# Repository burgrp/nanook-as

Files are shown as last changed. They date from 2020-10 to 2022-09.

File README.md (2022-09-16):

# nanook-as
NANOOK analog sensors board

|COLD |WATER IN |WATER OUT|FRIGO IN|FRIGO OUT|
|---|---|---|---|---|
| | R5 | R6 | R7 | R8 |
| t |-15..15  |-15..15  |-15..15 |-15..15  |
| R |56k |56k |56k |56k |

|HOT |WATER IN |WATER OUT|FRIGO IN|FRIGO OUT|
|---|---|---|---|---|
| | R5 | R6 | R7 | R8 |
| t |10..60 |10..70 |10..130 |10..60 |
| R1 |4k7 |4k7 |1k5 |4k7 |

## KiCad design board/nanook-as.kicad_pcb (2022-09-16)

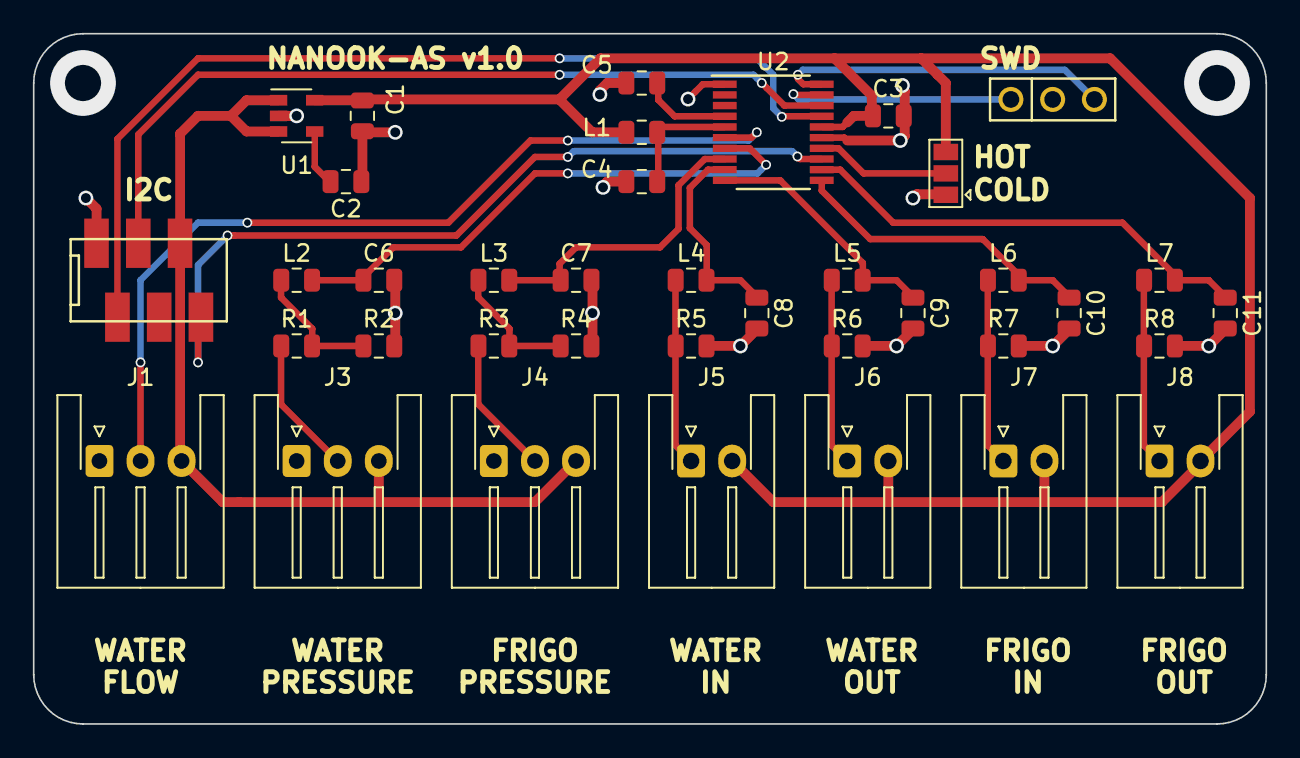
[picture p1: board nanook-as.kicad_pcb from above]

Board: 2 copper layers, 75.0 x 42.0 mm, 38 parts (0 on the bottom side), 27 nets.

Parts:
C1: 1u; C_0805_2012Metric
C2: 10n; C_0805_2012Metric
C3, C4, C5, C6, C7, C8, C9, C10, C11: 100n; C_0805_2012Metric
J1: Water Flow; JST_XH_S3B-XH-A-1_1x03_P2.50mm_Horizontal
J2: Address; SolderJumper-3_P1.3mm_Open_Pad1.0x1.5mm
J3, J4: Conn_01x03; JST_XH_S3B-XH-A-1_1x03_P2.50mm_Horizontal
J5, J6, J7, J8: Conn_01x02; JST_XH_S2B-XH-A-1_1x02_P2.50mm_Horizontal
L1, L2, L3, L4, L5, L6, L7: 22uH; L_0805_2012Metric
R1, R3: 4k7; R_0805_2012Metric
R2, R4: 10k; R_0805_2012Metric
R5, R6, R7, R8: (README.md); R_0805_2012Metric
U1: SPX3819; SOT-23-5
U2: STM32F030F4Px; TSSOP-20_4.4x6.5mm_P0.65mm
X1: I2C-6P; Micro-Match-FOB-6
X2: SWD

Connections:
+3V3: C1.2, C3.1, J2.3 (B), J5.2, J6.2, J7.2, J8.2, L1.1, U1.5 (VOUT), U2.16 (VDD)
+5V: J1.3, J3.3, J4.3, U1.1 (VIN), U1.3 (EN), X1.5 (5V)
/ALERT: U2.13 (PA7), X1.6 (ALERT)
/Frigo In/ADC-IN: C10.1, L6.2, U2.11 (PA5)
/Frigo Out/ADC-IN: C11.1, L7.2, U2.12 (PA6)
/Frigo Pressure/ADC-IN: C7.1, L3.2, U2.8 (PA2)
/SCL: U2.17 (PA9), X1.2 (SCL)
/SDA: U2.18 (PA10), X1.3 (SDA)
/SWCLK: U2.20 (PA14), X2.3 (SWCLK)
/SWDIO: U2.19 (PA13), X2.1 (SWDIO)
/Water In/ADC-IN: C8.1, L4.2, U2.9 (PA3)
/Water Out/ADC-IN: C9.1, L5.2, U2.10 (PA4)
/Water Pressure/ADC-IN: C6.1, L2.2, U2.7 (PA1)
GND: C1.1, C2.1, C3.2, C4.1, C5.2, C6.2, C7.2, C8.2, C9.2, C10.2, C11.2, J1.1, J2.1 (A), J3.1, J4.1, R2.2, R4.2, R5.2, R6.2, R7.2, R8.2, U1.2 (GND), U2.1 (BOOT0), U2.15 (VSS), X1.1 (GND), X2.2 (GND)
unnamed: J1.2, U2.6 (PA0)
unnamed: J2.2 (C), U2.14 (PB1)
unnamed: J3.2, R1.1
unnamed: J4.2, R3.1
unnamed: J5.1, L4.1, R5.1
unnamed: J6.1, L5.1, R6.1
unnamed: J7.1, L6.1, R7.1
unnamed: J8.1, L7.1, R8.1
unnamed: L2.1, R1.2, R2.1
unnamed: L3.1, R3.2, R4.1
unnamed: C2.2, U1.4 (BP)
unnamed: C5.1, U2.4 (NRST)
unnamed: C4.2, L1.2, U2.5 (VDDA)

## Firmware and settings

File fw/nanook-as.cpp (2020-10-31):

#include <climits>

const int analogSensCount = 8;
const int analogSensBaseIdx = 1;	

class IAS3 {

	iwdg::Driver iwdg;
	short data[1 + analogSensCount];

public:

	i2c::hw::BufferedSlave i2c;
	FrequencyMeter frequencyMeter;
	PeriodicAdc adc;

	void init(volatile target::i2c::Peripheral* peripheral, int address) {
		for (int i = 0; i < sizeof(data) / sizeof(data[0]); i++) {
			data[i] = 0;
		}
		iwdg.init();
		i2c.init(peripheral, address, NULL, 0, (unsigned char*)&data, sizeof(data));
		frequencyMeter.init(0, &data[0]);
		adc.init(&data[1], analogSensCount, analogSensBaseIdx);		
	}

};

IAS3 ias3;

void interruptHandlerI2C1() {
	ias3.i2c.handleInterrupt();
}

void interruptHandlerADC() {	
	ias3.adc.handleInterrupt();
}

void interruptHandlerEXTI0_1() {
	ias3.frequencyMeter.handleInterrupt();
}

void initApplication() {

	target::RCC.AHBENR.setIOPAEN(true);
	target::RCC.AHBENR.setIOPBEN(true);
	
	// I2C peripheral
	target::GPIOA.AFRH.setAFRH(9, 4);
	target::GPIOA.AFRH.setAFRH(10, 4);
	target::GPIOA.MODER.setMODER(9, 2);
	target::GPIOA.MODER.setMODER(10, 2);
	target::RCC.APB1ENR.setC_EN(1, 1);
	target::NVIC.ISER.setSETENA(1 << target::interrupts::External::I2C1);

	// ADC peripheral
	target::RCC.APB2ENR.setADCEN(1);
	target::NVIC.ISER.setSETENA(1 << target::interrupts::External::ADC);

	// EXTI for frequency meter	
	target::GPIOA.MODER.setMODER(0, 0);
	target::GPIOA.PUPDR.setPUPDR(0, 1);
	target::SYSCFG.EXTICR1.setEXTI(0, 0);
	target::NVIC.ISER.setSETENA(1 << target::interrupts::External::EXTI0_1);

	// check address switch
	const int addrPin = 1;
	volatile target::gpio_b_f::Peripheral* addrPort = &target::GPIOB;
	int address;
	addrPort->MODER.setMODER(addrPin, 0);
	addrPort->PUPDR.setPUPDR(addrPin, 1);
	for (volatile int c = 0; c < 1000; c++);
	if (addrPort->IDR.getIDR(addrPin) == 0) {
		address = 0x70;
	} else {
		addrPort->PUPDR.setPUPDR(addrPin, 2);
		for (volatile int c = 0; c < 1000; c++);
		if (addrPort->IDR.getIDR(addrPin) == 1) {
			address = 0x71;
		} else {
			address = 0x72;
		}
	}

	ias3.init(&target::I2C1, address);	
}

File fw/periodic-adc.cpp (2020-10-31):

short* vrefintCal = (short*)0x1FFFF7BA;

class PeriodicAdc {
	
	short* target;
	int analogSensCount; 
	int analogSensBaseIdx;

	int sensorIdx = 0;

public:

	void init(short* target, int analogSensCount, int analogSensBaseIdx) {

		target[analogSensCount - 1] = *vrefintCal;

		this->target = target;
		this->analogSensCount = analogSensCount;
		this->analogSensBaseIdx = analogSensBaseIdx;
		for (int c = 0; c < analogSensCount; c++) {
			target::GPIOA.MODER.setMODER(c + analogSensBaseIdx, 3);
		}

        target::ADC.CR.setADEN(1);
        target::ADC.CFGR2 = 1 << 30; // CKMODE[1:0] = 01, broken svd definition
        target::ADC.SMPR.setSMPR(7);
        target::ADC.IER.setEOCIE(1);
		target::ADC.CCR.setVREFEN(1);

        startAdcConversion();
	}

	void startAdcConversion() {
		int channelIdx = sensorIdx == analogSensCount - 2? 17: sensorIdx + analogSensBaseIdx;
		target::ADC.CHSELR.setCHSEL(channelIdx, true);
		target::ADC.CR.setADSTART(1);
	}

    void handleInterrupt() { 
        if (target::ADC.ISR.getEOC()) {
			int avg = (target::ADC.DR.getDATA() + this->target[sensorIdx]) / 2;
            this->target[sensorIdx] = avg;
            sensorIdx++;
            if (sensorIdx >= analogSensCount - 1) { // skip the last slot - it is set already by constant vrefintCal
                sensorIdx = 0;
            }    
			startAdcConversion();        
    	}
    }

};
